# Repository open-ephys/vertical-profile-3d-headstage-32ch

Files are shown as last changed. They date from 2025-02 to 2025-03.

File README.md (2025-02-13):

# vertical-profile-3d-headstage-32ch
Design files of a 32 channels headstage with 3D orientation using the same Intan's form factor.

## Licensing

The designs, documentation, and photos available in this repository are free: you can redistribute it and/or modify it under the terms of the used license.
Check the file named LICENSE.

<br />This work is licensed under a <a rel="license" href="http://creativecommons.org/licenses/by-nc-sa/3.0/igo/">Creative Commons Attribution-NonCommercial-ShareAlike 3.0 IGO License</a>.

[1]: https://docs.google.com/spreadsheets/d/1aobmmEzBDethzIlrm1eg0eYkBqlyX3s9WbA9KgRwVQI/edit?usp=sharing

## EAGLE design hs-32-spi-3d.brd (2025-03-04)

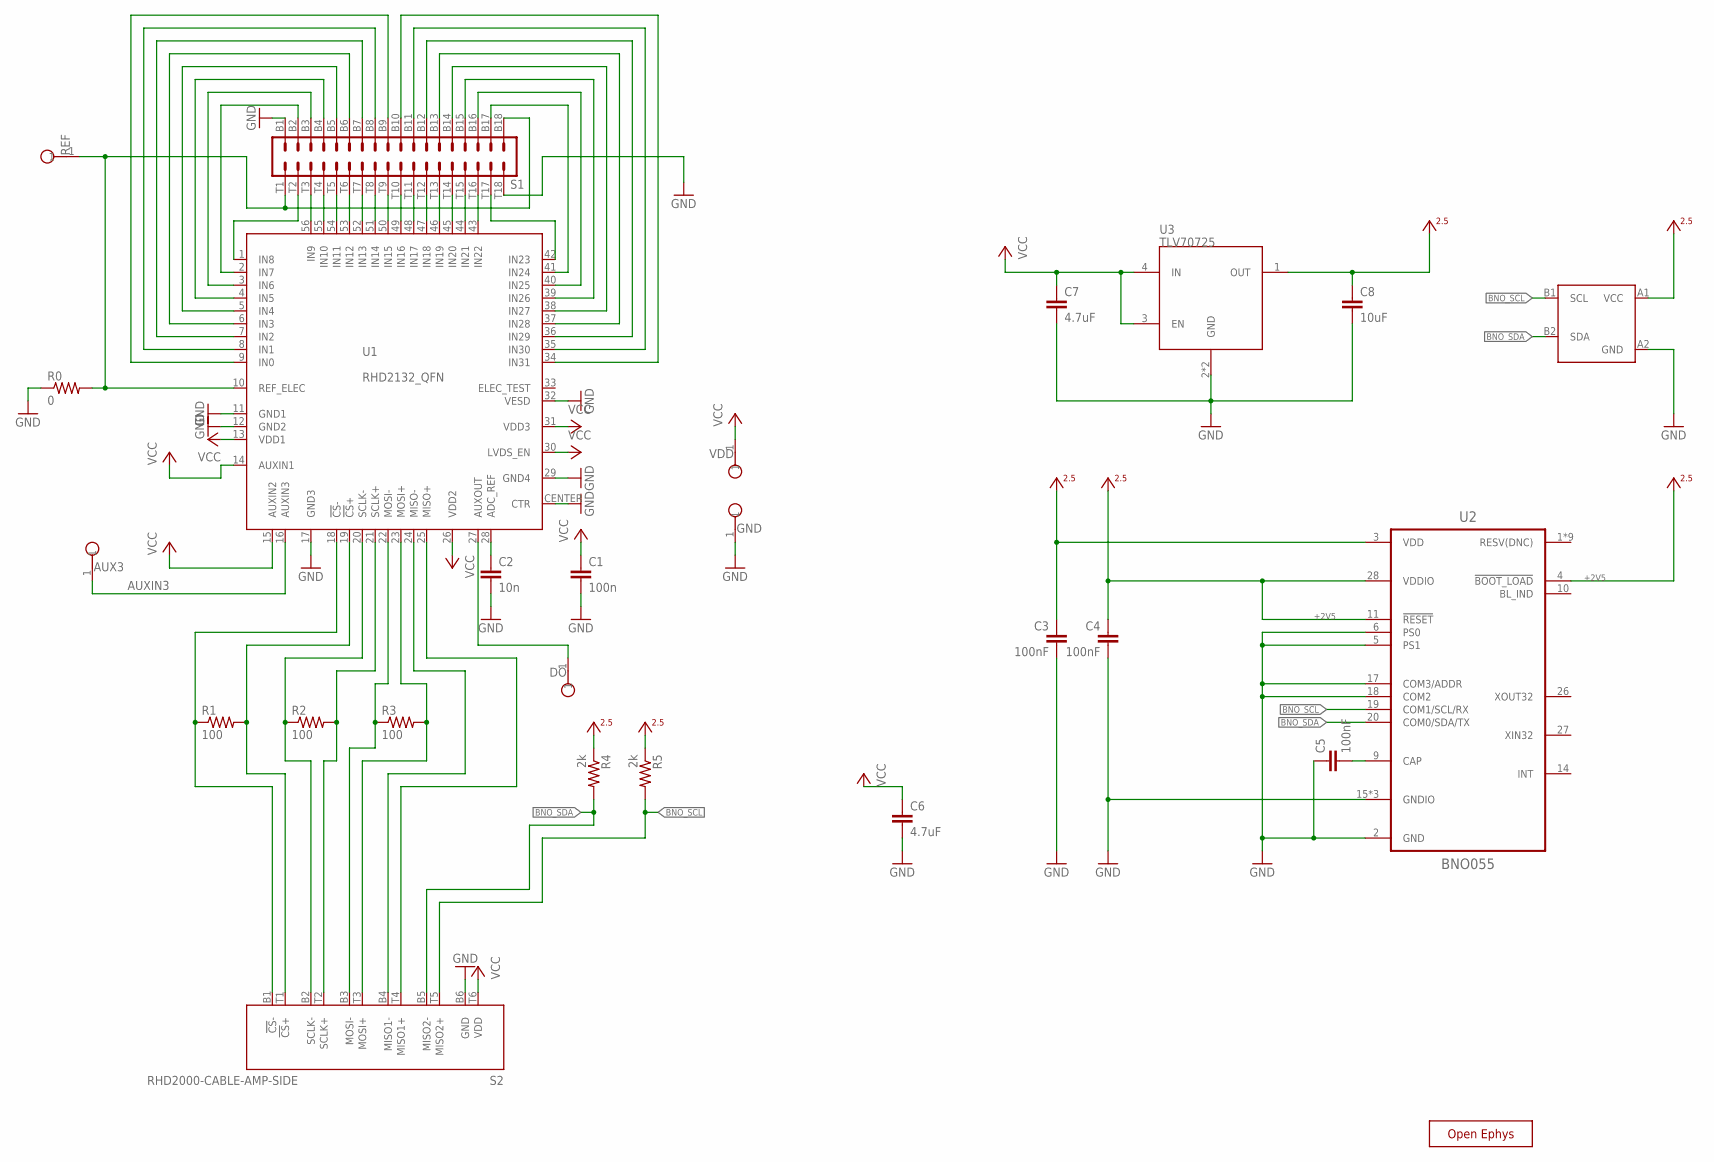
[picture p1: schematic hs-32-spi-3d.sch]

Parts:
AUX3: TESTPOINT_SMALL
C1: 100n; 0402
C2: 10n; 0402
C3, C4: 100nF; 0402T
C5: 100nF; 0201T
C6: 4.7uF; 0402
C7: 4.7uF; 0402T; PARTNO CL05A105KO5NNNC
C8: 10uF; 0402T; PARTNO CL05A106MQ5NUNC
DO: TESTPOINT_SMALL
GND: TESTPOINT_SMALL
R0: 0; 0402
R1, R2, R3: 100; 0402
R4, R5: 2k; 0201T
REF: TESTPOINT_SMALL
S1: OMNETICS_A79025
S2: RHD2000-CABLE-AMP-SIDE; OMNETICS_PZN-12-AA
U1: RHD2132_QFN; QFN56_8_X_8_LARGE
U2: BNO055; LGA-28-3.8X5.2
U3: TLV70725; X2SON
U4: 24CW640T-I/CS0668; 4-BALL_WAFFER_0.4MMX0.4MM
VDD: TESTPOINT_SMALL
X: OE-LOGO_3.5X2.5; OE-LOGO-3.5X2.5

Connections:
+2V5: C3.1, C4.1, C8.1, R4.1, R5.1, U2.3 (VDD), U2.4 (!BOOT_LOAD), U2.11 (!RESET), U2.28 (VDDIO), U3.1 (OUT), U4.A1 (VCC)
AUXIN3: AUX3.1, U1.16 (AUXIN3)
BNO_SCL: R5.2, S2.T5 (MISO2+), U2.19 (COM1/SCL/RX), U4.B1 (SCL)
BNO_SDA: R4.2, S2.B5 (MISO2-), U2.20 (COM0/SDA/TX), U4.B2 (SDA)
GND: C1.2, C2.2, C3.2, C4.2, C5.1, C6.2, C7.2, C8.2, GND.1, R0.1, S1.B1, S1.T18, S2.B6 (GND), U1.11 (GND1), U1.12 (GND2), U1.17 (GND3), U1.29 (GND4), U1.32 (VESD), U1.CENTER (CTR), U2.2 (GND), U2.5 (PS1), U2.6 (PS0), U2.15 (GNDIO), U2.16 (GNDIO), U2.17 (COM3/ADDR), U2.18 (COM2), U2.25 (GNDIO), U3.2 (GND), U3.PAD (GND), U4.A2 (GND)
unnamed: R0.2, REF.1, S1.B18, S1.T1, U1.10 (REF_ELEC)
unnamed: S1.B3, U1.3 (IN6)
unnamed: S1.B2, U1.2 (IN7)
unnamed: S1.B4, U1.4 (IN5)
unnamed: S1.B5, U1.5 (IN4)
unnamed: S1.B6, U1.6 (IN3)
unnamed: S1.B7, U1.7 (IN2)
unnamed: S1.B8, U1.8 (IN1)
unnamed: S1.B9, U1.9 (IN0)
unnamed: S1.B10, U1.34 (IN31)
unnamed: R1.1, S2.B1 (!CS!-), U1.18 (!CS!-)
unnamed: S1.B17, U1.41 (IN24)
unnamed: S1.B16, U1.40 (IN25)
unnamed: S1.B15, U1.39 (IN26)
unnamed: S1.B14, U1.38 (IN27)
unnamed: S1.B13, U1.37 (IN28)
unnamed: S1.B12, U1.36 (IN29)
unnamed: S1.B11, U1.35 (IN30)
unnamed: S1.T9, U1.50 (IN15)
unnamed: S1.T8, U1.51 (IN14)
unnamed: S1.T7, U1.52 (IN13)
unnamed: S1.T3, U1.56 (IN9)
unnamed: S1.T4, U1.55 (IN10)
unnamed: S1.T5, U1.54 (IN11)
unnamed: S1.T6, U1.53 (IN12)
unnamed: S1.T10, U1.49 (IN16)
unnamed: S1.T11, U1.48 (IN17)
unnamed: S1.T12, U1.47 (IN18)
unnamed: S1.T13, U1.46 (IN19)
unnamed: S1.T14, U1.45 (IN20)
unnamed: S1.T15, U1.44 (IN21)
unnamed: S1.T16, U1.43 (IN22)
unnamed: S1.T2, U1.1 (IN8)
unnamed: S1.T17, U1.42 (IN23)
unnamed: R1.2, S2.T1 (!CS!+), U1.19 (!CS!+)
unnamed: R2.1, S2.B2 (SCLK-), U1.20 (SCLK-)
unnamed: R2.2, S2.T2 (SCLK+), U1.21 (SCLK+)
unnamed: R3.1, S2.B3 (MOSI-), U1.22 (MOSI-)
unnamed: R3.2, S2.T3 (MOSI+), U1.23 (MOSI+)
unnamed: S2.B4 (MISO1-), U1.24 (MISO-)
unnamed: S2.T4 (MISO1+), U1.25 (MISO+)
unnamed: C2.1, U1.28 (ADC_REF)
unnamed: DO.1, U1.27 (AUXOUT)
unnamed: C5.2, U2.9 (CAP)
VCC: C1.1, C6.1, C7.1, S2.T6 (VDD), U1.13 (VDD1), U1.14 (AUXIN1), U1.15 (AUXIN2), U1.26 (VDD2), U1.30 (LVDS_EN), U1.31 (VDD3), U3.3 (EN), U3.4 (IN), VDD.1

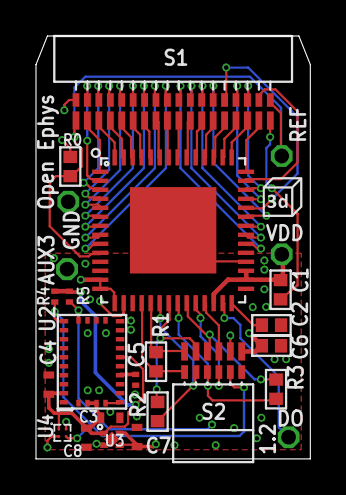
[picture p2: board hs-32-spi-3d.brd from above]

Board: 4 copper layers, 15.2 x 23.5 mm, 26 parts (1 on the bottom side), 50 nets.

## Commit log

2023-10-07 Added PCB design files.
    [hs-32-spi-3d.brd, hs-32-spi-3d.sch]
2023-10-07 Increased minimum drill to 0.25 mm.
    Also created a pad for the AUXIN3.
    [hs-32-spi-3d.brd, hs-32-spi-3d.sch]
2023-10-07 Added components centroids.
    [hs-32-spi-3d_centroid.csv]
2023-10-07 Corrected C6 and C7 values to 4.7uF.
    [hs-32-spi-3d.brd, hs-32-spi-3d.sch]
2024-10-17 Added 3d logo.
    [hs-32-spi-3d.brd, hs-32-spi-3d.sch]
2025-02-18 Added EEPROM.
    [hs-32-spi-3d.brd, hs-32-spi-3d.sch]
2025-03-04 Cleaned DRC.
    [hs-32-spi-3d.brd]
2025-03-04 Minor details regarding capacitors' nomenclature.
    [hs-32-spi-3d.brd, hs-32-spi-3d.sch]
2025-03-04 Updated production files.
    [hs-32-spi-3d_centroid.csv]
